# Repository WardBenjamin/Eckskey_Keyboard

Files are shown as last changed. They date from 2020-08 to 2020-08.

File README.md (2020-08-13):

# Eckskey

The Eckskey (pronounced "x key") keyboard is an open source 74% mechanical keyboard, designed with an emphasis on electrical correctness and manufacturability, and with some fun tricks.

## Design Philosophy

Throughout the design, electrical correctness will be emphasized, including proper differential pair routing (within the constraints of a two layer design), ground planes, current carrying capacity, and oscillator routing. The board is manufacturable with 6mil trace/space, accomplishable with 1oz two layer designs by local vendors in your area (including the United States) as well as at the cheapest Chinese vendors like JLCPCB, PCBway, and AllPCB.

The base keyboard is designed to be made in two pieces, meaning that it can be assembled in a small/cheap reflow oven like a ControLEO 3 toaster oven conversion or the common Chinese T962 variants. This adds a small amount of BOM cost and would probably increase the cost at quantity, but enables wider access.

This keyboard is NOT meant to be assembled by the typical r/MK hobbyist - it includes QFN and 0603 parts which require a stencil and a pair of tweezers and a pick and place machine to assemble reasonably. You CAN solder these by hand or with hot air but it is difficult. 

## Fun tricks

In total, the base keyboard is a 74% design, meaning that it retains alphanumerics, function keys (F1-F12), and symbols. In addition, the bottom row has been modified to add a left function key (FN) between left control and META/Windows and a right print screen key between menu and right control. Since it still uses a normal 6.25U spacebar, the right keys in the bottom of the row have each been shrunk to 1U. The function keys have been shifted leftwards and collapsed in order to make space for 1U insert and delete keys above backspace. This retains all common functionality of a 100% keyboard except for nav cluster, media keys, and numpad.

The base keyboard includes an integrated USB hub to allow for additional modules to be connected. Two modules will be made - a numpad and nav cluster+media keys. These will technically be separate keyboards, connected via USB-C and magnetic mounting, and can be used standalone as well. These keyboards also have access to the function key by taking advantage of the SBU pins of the USB-C connectors which are normally unused in a USB 1.1/2.0 implementation.

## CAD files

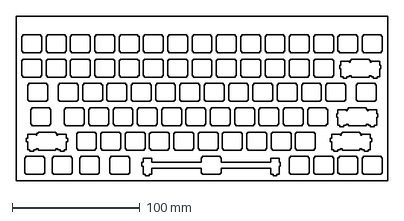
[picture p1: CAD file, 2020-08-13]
mechanical/eckskey_base_74.dxf
290.7 x 128.8 mm

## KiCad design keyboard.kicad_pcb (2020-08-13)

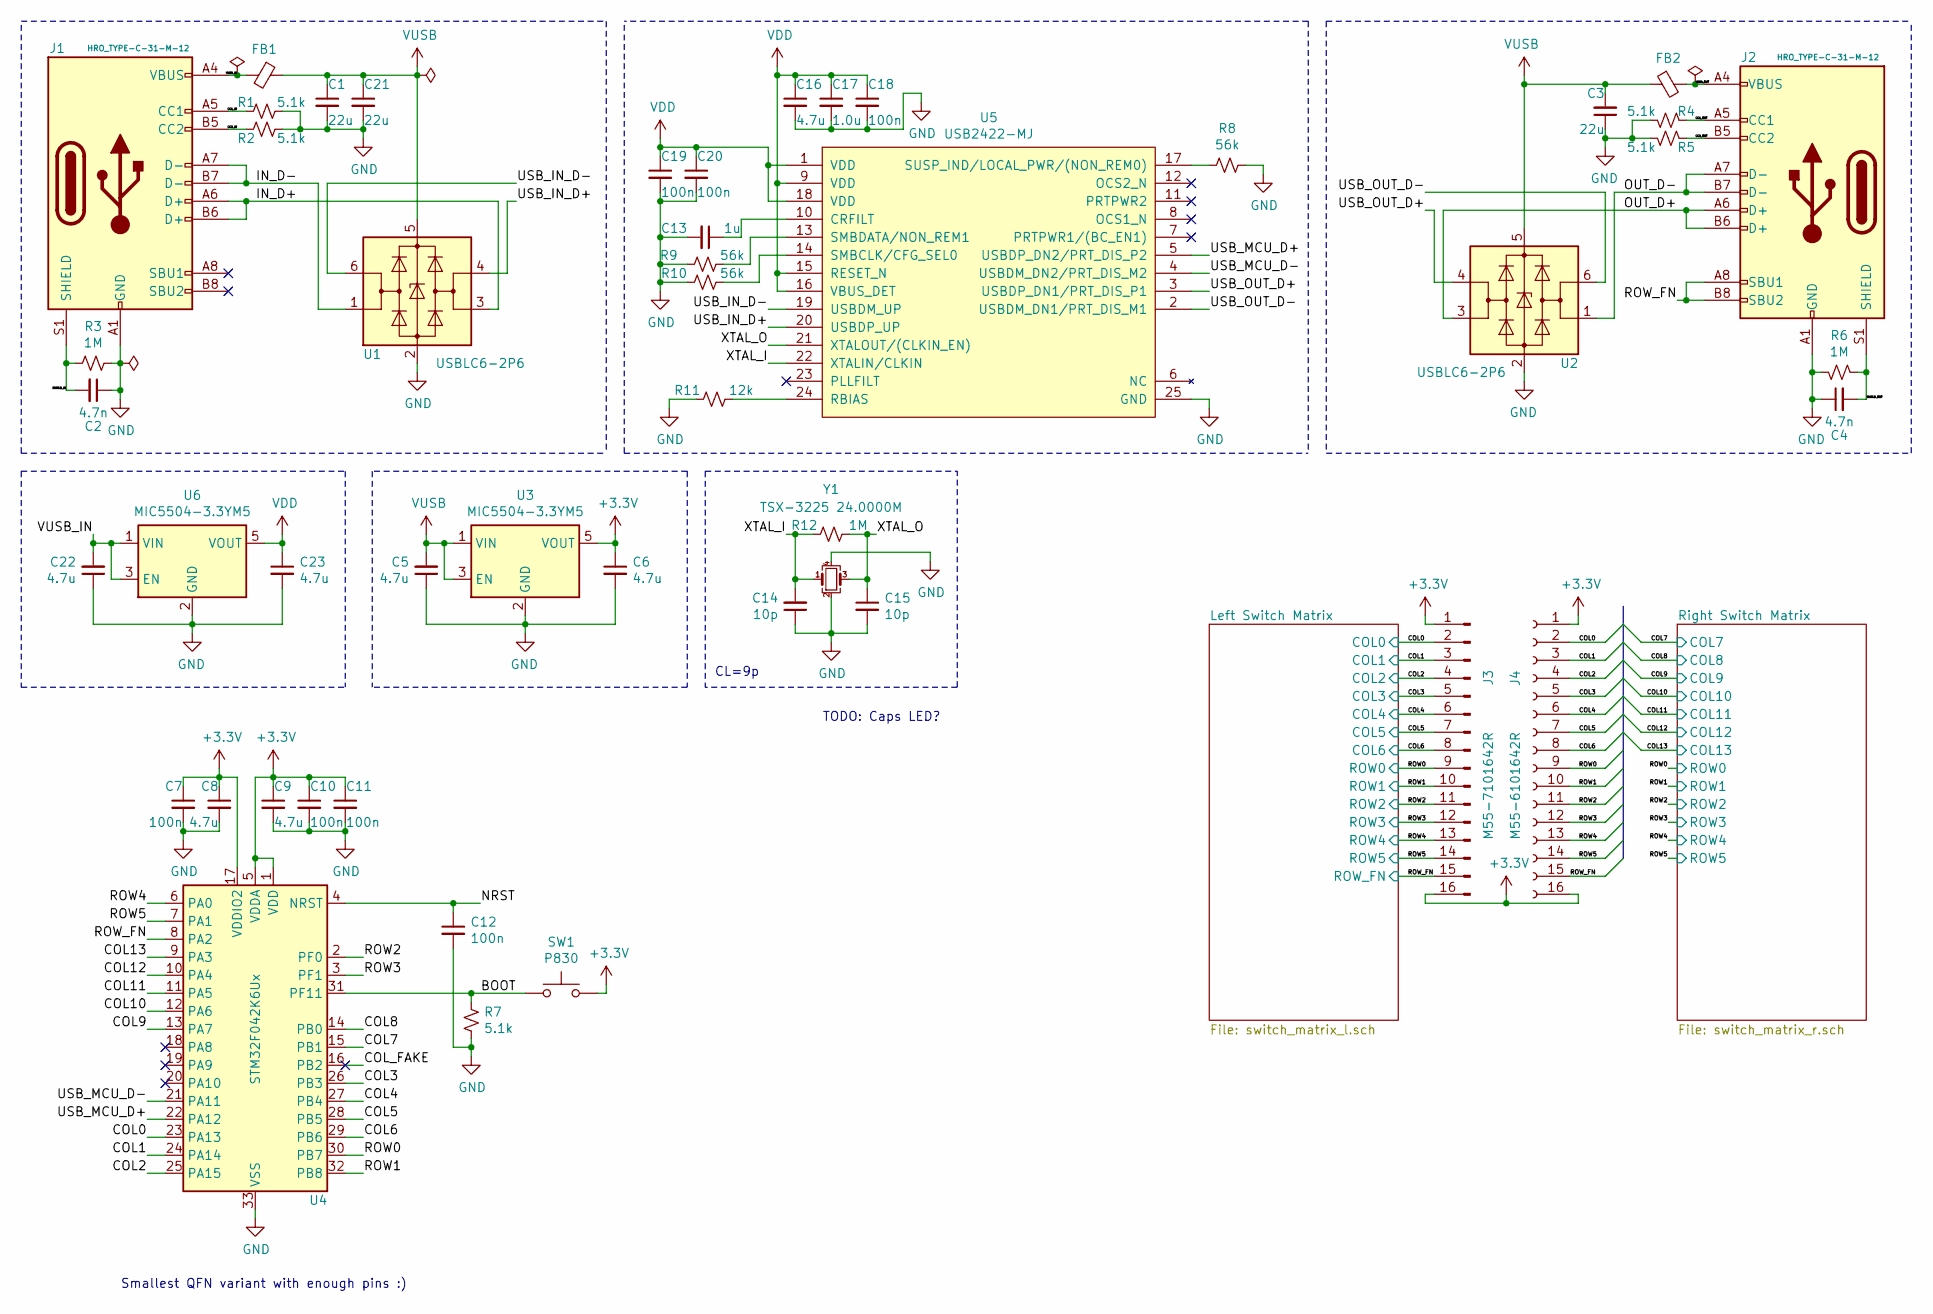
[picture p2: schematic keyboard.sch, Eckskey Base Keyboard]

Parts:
C1, C3, C21: 22u; C_0603_1608Metric
C2, C4: 4.7n; C_0603_1608Metric
C5, C6, C8, C9, C16, C22, C23: 4.7u; C_0603_1608Metric
C7, C10, C11, C12, C18, C19, C20: 100n; C_0603_1608Metric
C13: 1u; C_0603_1608Metric
C14, C15: 10p; C_0603_1608Metric
C17: 1.0u; C_0603_1608Metric
FB1, FB2: Ferrite_Bead_Small; L_0603_1608Metric
J1, J2: HRO_TYPE-C-31-M-12; USB_C_Receptacle_HRO_TYPE-C-31-M-12
J3: M55-7101642R; M557101642R
J4: M55-6101642R; M556101642R
R1, R2, R4, R5, R7: 5.1k; R_0603_1608Metric
R3, R6, R12: 1M; R_0603_1608Metric
R8, R9, R10: 56k; R_0603_1608Metric
R11: 12k; R_0603_1608Metric
SW1: P830; SW_SPST_PTS830
U1, U2: USBLC6-2P6; SOT-666
U3, U6: MIC5504-3.3YM5; SOT-23-5
U4: STM32F042K6Ux; QFN-32-1EP_5x5mm_P0.5mm_EP3.45x3.45mm
U5: USB2422-MJ; QFN-24-1EP_4x4mm_P0.5mm_EP2.7x2.7mm_ThermalVias
Y1: TSX-3225 24.0000M; Crystal_SMD_SeikoEpson_TSX3225-4Pin_3.2x2.5mm

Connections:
+3V3: C6.1, C7.1, C8.1, C9.1, C10.1, C11.1, J3.1, J3.16, J4.1, J4.16, SW1.2, U3.5 (VOUT), U4.1 (VDD), U4.5 (VDDA), U4.17 (VDDIO2); also elsewhere on the board
/BOOT: R7.1, SW1.1, U4.31 (PF11)
/CC1_IN: J1.A5 (CC1), R1.2
/CC1_OUT: J2.A5 (CC1), R4.2
/CC2_IN: J1.B5 (CC2), R2.2
/CC2_OUT: J2.B5 (CC2), R5.2
/COL0: J3.2, J4.2, U4.23 (PA13); also elsewhere on the board
/COL1: J3.3, J4.3, U4.24 (PA14); also elsewhere on the board
/COL2: J3.4, J4.4, U4.25 (PA15); also elsewhere on the board
/COL3: J3.5, J4.5, U4.26 (PB3); also elsewhere on the board
/COL4: J3.6, J4.6, U4.27 (PB4); also elsewhere on the board
/COL5: J3.7, J4.7, U4.28 (PB5); also elsewhere on the board
/COL6: J3.8, J4.8, U4.29 (PB6); also elsewhere on the board
/COL7: U4.15 (PB1); also elsewhere on the board
/COL8: U4.14 (PB0); also elsewhere on the board
/COL9: U4.13 (PA7); also elsewhere on the board
/COL10: U4.12 (PA6); also elsewhere on the board
/COL11: U4.11 (PA5); also elsewhere on the board
/COL12: U4.10 (PA4); also elsewhere on the board
/COL13: U4.9 (PA3); also elsewhere on the board
/IN_D+: J1.A6 (D+), J1.B6 (D+), U1.3 (I/O2)
/IN_D-: J1.A7 (D-), J1.B7 (D-), U1.1 (I/O1)
/NRST: C12.1, U4.4 (NRST)
/OUT_D+: J2.A6 (D+), J2.B6 (D+), U2.3 (I/O2)
/OUT_D-: J2.A7 (D-), J2.B7 (D-), U2.1 (I/O1)
/ROW0: J3.9, J4.9, U4.30 (PB7); also elsewhere on the board
/ROW1: J3.10, J4.10, U4.32 (PB8); also elsewhere on the board
/ROW2: J3.11, J4.11, U4.2 (PF0); also elsewhere on the board
/ROW3: J3.12, J4.12, U4.3 (PF1); also elsewhere on the board
/ROW4: J3.13, J4.13, U4.6 (PA0); also elsewhere on the board
/ROW5: J3.14, J4.14, U4.7 (PA1); also elsewhere on the board
/ROW_FN: J2.A8 (SBU1), J2.B8 (SBU2), J3.15, J4.15, U4.8 (PA2); also elsewhere on the board
/SHIELD_IN: C2.2, J1.S1 (SHIELD), R3.2
/SHIELD_OUT: C4.2, J2.S1 (SHIELD), R6.2
/USB_IN_D+: U1.4 (I/O2), U5.20 (USBDP_UP)
/USB_IN_D-: U1.6 (I/O1), U5.19 (USBDM_UP)
/USB_MCU_D+: U4.22 (PA12), U5.5 (USBDP_DN2/PRT_DIS_P2)
/USB_MCU_D-: U4.21 (PA11), U5.4 (USBDM_DN2/PRT_DIS_M2)
/USB_OUT_D+: U2.4 (I/O2), U5.3 (USBDP_DN1/PRT_DIS_P1)
/USB_OUT_D-: U2.6 (I/O1), U5.2 (USBDM_DN1/PRT_DIS_M1)
/VUSB_IN: C22.2, FB1.2, J1.A4 (VBUS), J1.A9 (VBUS), J1.B4 (VBUS), J1.B9 (VBUS), U6.1 (VIN), U6.3 (EN)
/VUSB_OUT: FB2.2, J2.A4 (VBUS), J2.A9 (VBUS), J2.B4 (VBUS), J2.B9 (VBUS)
/XTAL_I: C14.2, R12.2, U5.22 (XTALIN/CLKIN), Y1.1
/XTAL_O: C15.1, R12.1, U5.21 (XTALOUT/(CLKIN_EN)), Y1.3
GND: C1.2, C2.1, C3.1, C4.1, C5.1, C6.2, C7.2, C8.2, C9.2, C10.2, C11.2, C12.2, C13.2, C14.1, C15.2, C16.2, C17.2, C18.2, C19.2, C20.2, C21.2, C22.1, C23.2, J1.A1 (GND), J1.A12 (GND), J1.B1 (GND), J1.B12 (GND), J2.A1 (GND), J2.A12 (GND), J2.B1 (GND), J2.B12 (GND), R1.1, R2.1, R3.1, R4.1, R5.1, R6.1, R7.2, R8.1, R9.2, R10.2, R11.2, U1.2 (GND), U2.2 (GND), U3.2 (GND), U4.33 (VSS), U5.25 (GND), U6.2 (GND), Y1.2, Y1.4
unnamed: C13.1, U5.10 (CRFILT)
unnamed: R8.2, U5.17 (SUSP_IND/LOCAL_PWR/(NON_REM0))
unnamed: R9.1, U5.13 (SMBDATA/NON_REM1)
unnamed: R10.1, U5.14 (SMBCLK/CFG_SEL0)
unnamed: R11.1, U5.24 (RBIAS)
VDD: C16.1, C17.1, C18.1, C19.1, C20.1, C23.1, U5.1 (VDD), U5.9 (VDD), U5.15 (RESET_N), U5.16 (VBUS_DET), U5.18 (VDD), U6.5 (VOUT)
VUSB: C1.1, C3.2, C5.2, C21.1, FB1.1, FB2.1, U1.5 (VBUS), U2.5 (VBUS), U3.1 (VIN), U3.3 (EN)

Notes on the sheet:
Smallest QFN variant with enough pins :)
CL=9p
TODO: Caps LED?

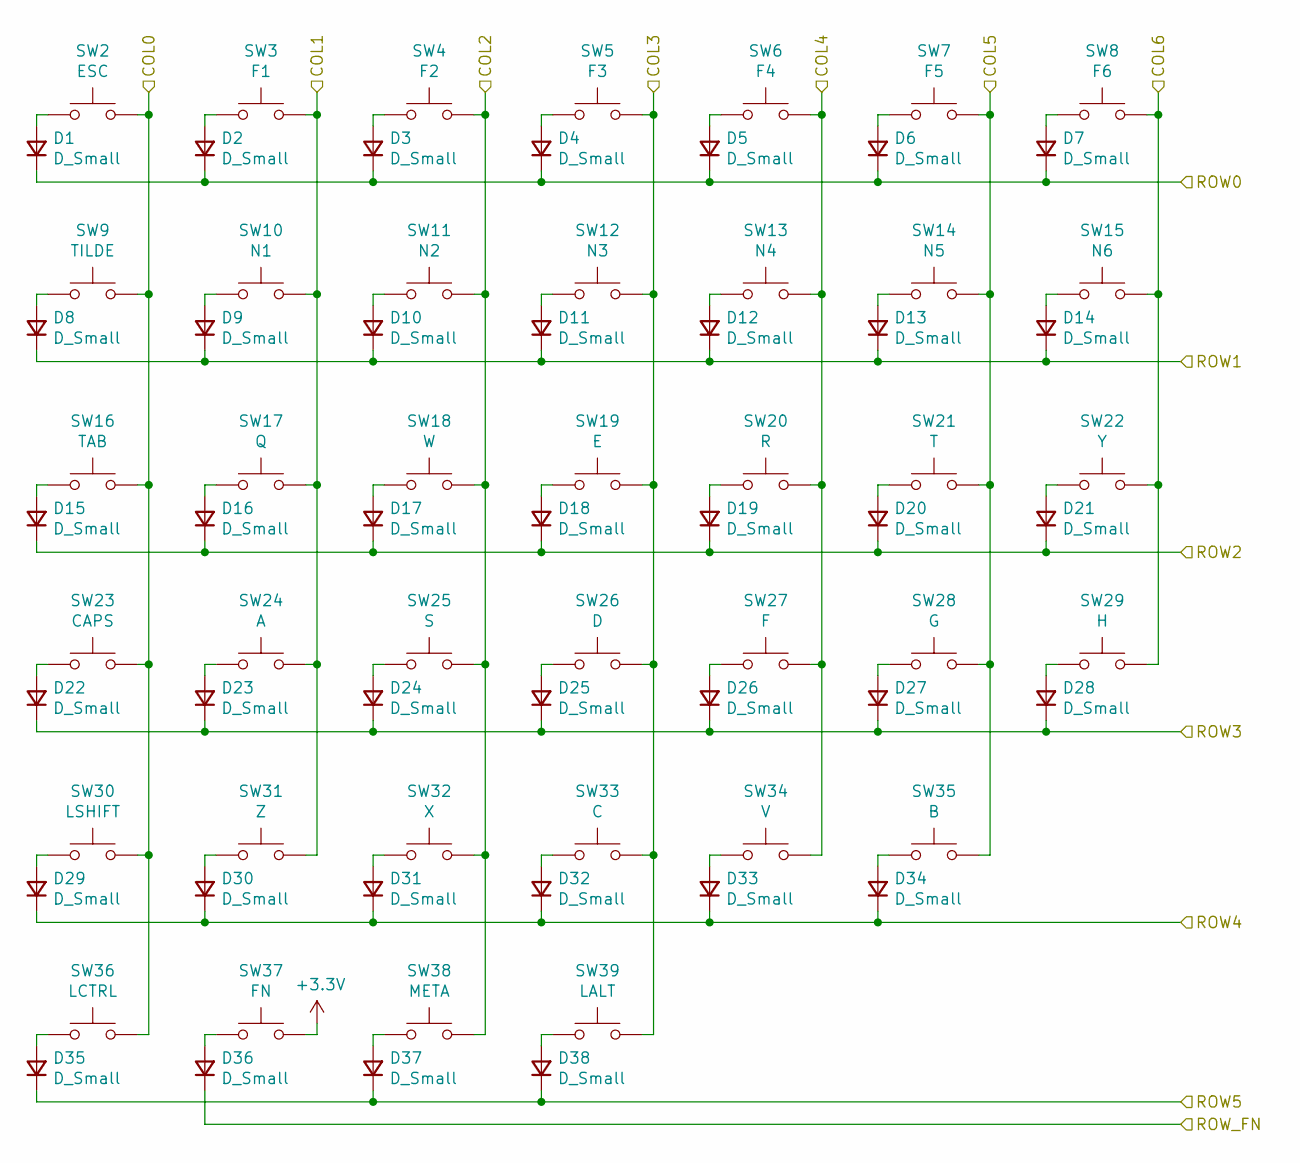
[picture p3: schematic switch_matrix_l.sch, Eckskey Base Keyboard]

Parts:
D1, D2, D3, D4, D5, D6, D7, D8, D9, D10, D11, D12, D13, D14, D15, D16, D17, D18, D19, D20, D21, D22, D23, D24, D25, D26, D27, D28, D29, D30, D31, D32, D33, D34, D35, D36, D37, D38: D_Small; D_SOD-123F
SW2: ESC; MX-1U
SW3: F1; MX-1U
SW4: F2; MX-1U
SW5: F3; MX-1U
SW6: F4; MX-1U
SW7: F5; MX-1U
SW8: F6; MX-1U
SW9: TILDE; MX-1U
SW10: N1; MX-1U
SW11: N2; MX-1U
SW12: N3; MX-1U
SW13: N4; MX-1U
SW14: N5; MX-1U
SW15: N6; MX-1U
SW16: TAB; MX-1.5U
SW17: Q; MX-1U
SW18: W; MX-1U
SW19: E; MX-1U
SW20: R; MX-1U
SW21: T; MX-1U
SW22: Y; MX-1U
SW23: CAPS; MX-1.75U
SW24: A; MX-1U
SW25: S; MX-1U
SW26: D; MX-1U
SW27: F; MX-1U
SW28: G; MX-1U
SW29: H; MX-1U
SW30: LSHIFT; MX-2.25U
SW31: Z; MX-1U
SW32: X; MX-1U
SW33: C; MX-1U
SW34: V; MX-1U
SW35: B; MX-1U
SW36: LCTRL; MX-1.25U
SW37: FN; MX-1U
SW38: META; MX-1.25U
SW39: LALT; MX-1.25U

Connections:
+3V3: SW37.2; also elsewhere on the board
/COL0: SW2.2, SW9.2, SW16.2, SW23.2, SW30.2, SW36.2; also elsewhere on the board
/COL1: SW3.2, SW10.2, SW17.2, SW24.2, SW31.2; also elsewhere on the board
/COL2: SW4.2, SW11.2, SW18.2, SW25.2, SW32.2, SW38.2; also elsewhere on the board
/COL3: SW5.2, SW12.2, SW19.2, SW26.2, SW33.2, SW39.2; also elsewhere on the board
/COL4: SW6.2, SW13.2, SW20.2, SW27.2, SW34.2; also elsewhere on the board
/COL5: SW7.2, SW14.2, SW21.2, SW28.2, SW35.2; also elsewhere on the board
/COL6: SW8.2, SW15.2, SW22.2, SW29.2; also elsewhere on the board
/ROW0: D1.1 (K), D2.1 (K), D3.1 (K), D4.1 (K), D5.1 (K), D6.1 (K), D7.1 (K); also elsewhere on the board
/ROW1: D8.1 (K), D9.1 (K), D10.1 (K), D11.1 (K), D12.1 (K), D13.1 (K), D14.1 (K); also elsewhere on the board
/ROW2: D15.1 (K), D16.1 (K), D17.1 (K), D18.1 (K), D19.1 (K), D20.1 (K), D21.1 (K); also elsewhere on the board
/ROW3: D22.1 (K), D23.1 (K), D24.1 (K), D25.1 (K), D26.1 (K), D27.1 (K), D28.1 (K); also elsewhere on the board
/ROW4: D29.1 (K), D30.1 (K), D31.1 (K), D32.1 (K), D33.1 (K), D34.1 (K); also elsewhere on the board
/ROW5: D35.1 (K), D37.1 (K), D38.1 (K); also elsewhere on the board
/ROW_FN: D36.1 (K); also elsewhere on the board
unnamed: D1.2 (A), SW2.1
unnamed: D2.2 (A), SW3.1
unnamed: D3.2 (A), SW4.1
unnamed: D4.2 (A), SW5.1
unnamed: D5.2 (A), SW6.1
unnamed: D6.2 (A), SW7.1
unnamed: D7.2 (A), SW8.1
unnamed: D8.2 (A), SW9.1
unnamed: D9.2 (A), SW10.1
unnamed: D10.2 (A), SW11.1
unnamed: D11.2 (A), SW12.1
unnamed: D12.2 (A), SW13.1
unnamed: D13.2 (A), SW14.1
unnamed: D14.2 (A), SW15.1
unnamed: D15.2 (A), SW16.1
unnamed: D16.2 (A), SW17.1
unnamed: D17.2 (A), SW18.1
unnamed: D18.2 (A), SW19.1
unnamed: D19.2 (A), SW20.1
unnamed: D20.2 (A), SW21.1
unnamed: D21.2 (A), SW22.1
unnamed: D22.2 (A), SW23.1
unnamed: D23.2 (A), SW24.1
unnamed: D24.2 (A), SW25.1
unnamed: D25.2 (A), SW26.1
unnamed: D26.2 (A), SW27.1
unnamed: D27.2 (A), SW28.1
unnamed: D28.2 (A), SW29.1
unnamed: D29.2 (A), SW30.1
unnamed: D30.2 (A), SW31.1
unnamed: D31.2 (A), SW32.1
unnamed: D32.2 (A), SW33.1
unnamed: D33.2 (A), SW34.1
unnamed: D34.2 (A), SW35.1
unnamed: D35.2 (A), SW36.1
unnamed: D36.2 (A), SW37.1
unnamed: D37.2 (A), SW38.1
unnamed: D38.2 (A), SW39.1

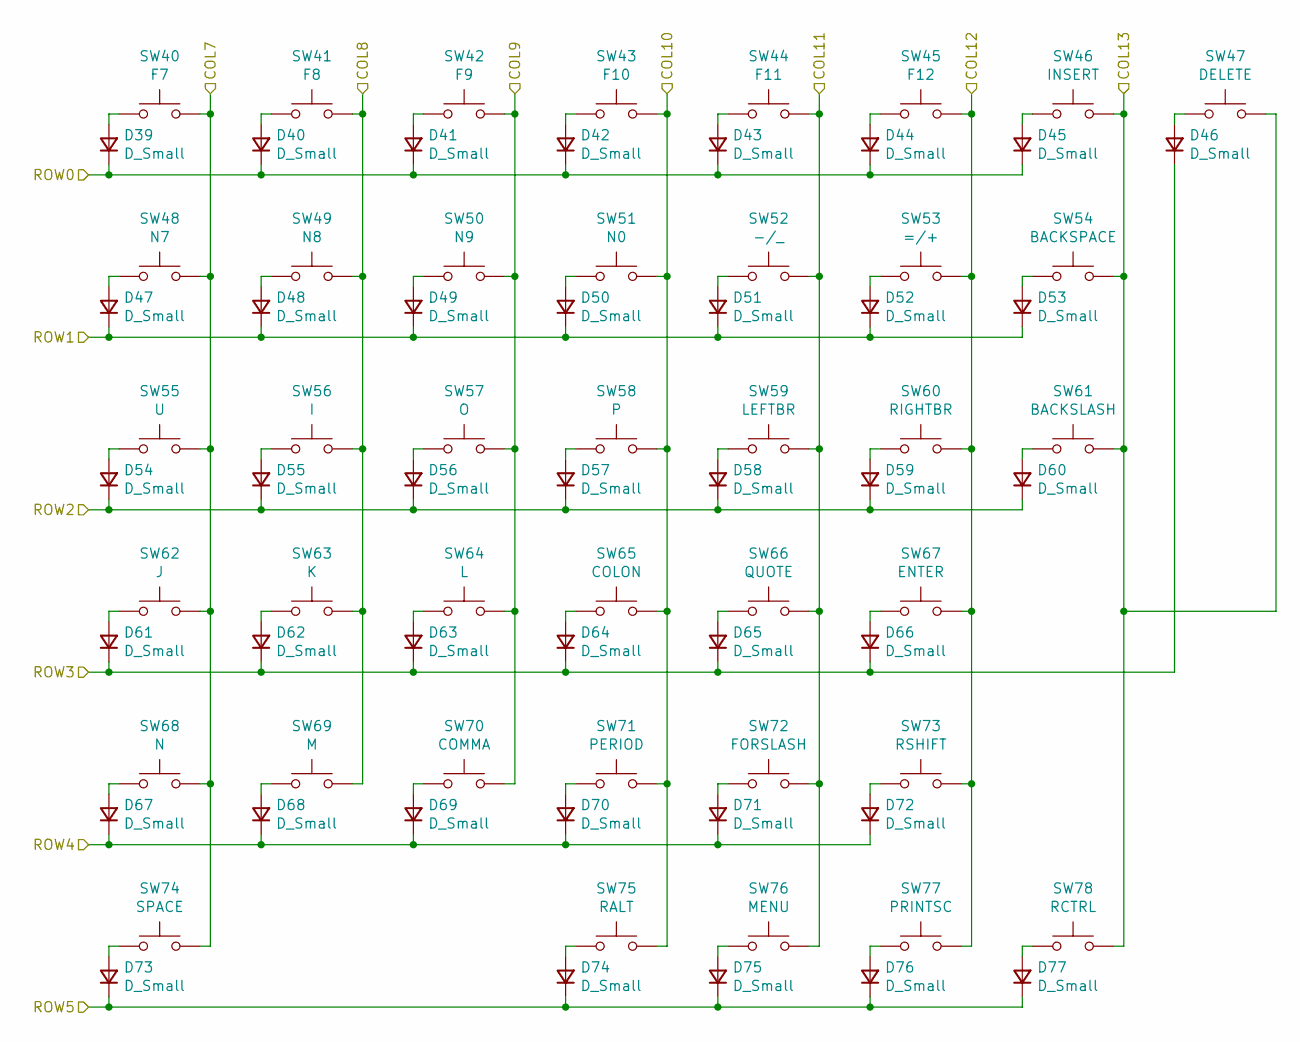
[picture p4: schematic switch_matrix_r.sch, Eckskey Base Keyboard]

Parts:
D39, D40, D41, D42, D43, D44, D45, D46, D47, D48, D49, D50, D51, D52, D53, D54, D55, D56, D57, D58, D59, D60, D61, D62, D63, D64, D65, D66, D67, D68, D69, D70, D71, D72, D73, D74, D75, D76, D77: D_Small; D_SOD-123F
SW40: F7; MX-1U
SW41: F8; MX-1U
SW42: F9; MX-1U
SW43: F10; MX-1U
SW44: F11; MX-1U
SW45: F12; MX-1U
SW46: INSERT; MX-1U
SW47: DELETE; MX-1U
SW48: N7; MX-1U
SW49: N8; MX-1U
SW50: N9; MX-1U
SW51: N0; MX-1U
SW52: -/_; MX-1U
SW53: =/+; MX-1U
SW54: BACKSPACE; MX-2U
SW55: U; MX-1U
SW56: I; MX-1U
SW57: O; MX-1U
SW58: P; MX-1U
SW59: LEFTBR; MX-1U
SW60: RIGHTBR; MX-1U
SW61: BACKSLASH; MX-1.5U
SW62: J; MX-1U
SW63: K; MX-1U
SW64: L; MX-1U
SW65: COLON; MX-1U
SW66: QUOTE; MX-1U
SW67: ENTER; MX-2.25U
SW68: N; MX-1U
SW69: M; MX-1U
SW70: COMMA; MX-1U
SW71: PERIOD; MX-1U
SW72: FORSLASH; MX-1U
SW73: RSHIFT; MX-2.75U
SW74: SPACE; MX-6.25U
SW75: RALT; MX-1U
SW76: MENU; MX-1U
SW77: PRINTSC; MX-1U
SW78: RCTRL; MX-1U

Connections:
/COL7: SW40.2, SW48.2, SW55.2, SW62.2, SW68.2, SW74.2; also elsewhere on the board
/COL8: SW41.2, SW49.2, SW56.2, SW63.2, SW69.2; also elsewhere on the board
/COL9: SW42.2, SW50.2, SW57.2, SW64.2, SW70.2; also elsewhere on the board
/COL10: SW43.2, SW51.2, SW58.2, SW65.2, SW71.2, SW75.2; also elsewhere on the board
/COL11: SW44.2, SW52.2, SW59.2, SW66.2, SW72.2, SW76.2; also elsewhere on the board
/COL12: SW45.2, SW53.2, SW60.2, SW67.2, SW73.2, SW77.2; also elsewhere on the board
/COL13: SW46.2, SW47.2, SW54.2, SW61.2, SW78.2; also elsewhere on the board
/ROW0: D39.1 (K), D40.1 (K), D41.1 (K), D42.1 (K), D43.1 (K), D44.1 (K), D45.1 (K); also elsewhere on the board
/ROW1: D47.1 (K), D48.1 (K), D49.1 (K), D50.1 (K), D51.1 (K), D52.1 (K), D53.1 (K); also elsewhere on the board
/ROW2: D54.1 (K), D55.1 (K), D56.1 (K), D57.1 (K), D58.1 (K), D59.1 (K), D60.1 (K); also elsewhere on the board
/ROW3: D46.1 (K), D61.1 (K), D62.1 (K), D63.1 (K), D64.1 (K), D65.1 (K), D66.1 (K); also elsewhere on the board
/ROW4: D67.1 (K), D68.1 (K), D69.1 (K), D70.1 (K), D71.1 (K), D72.1 (K); also elsewhere on the board
/ROW5: D73.1 (K), D74.1 (K), D75.1 (K), D76.1 (K), D77.1 (K); also elsewhere on the board
unnamed: D39.2 (A), SW40.1
unnamed: D40.2 (A), SW41.1
unnamed: D41.2 (A), SW42.1
unnamed: D42.2 (A), SW43.1
unnamed: D43.2 (A), SW44.1
unnamed: D44.2 (A), SW45.1
unnamed: D45.2 (A), SW46.1
unnamed: D46.2 (A), SW47.1
unnamed: D47.2 (A), SW48.1
unnamed: D48.2 (A), SW49.1
unnamed: D49.2 (A), SW50.1
unnamed: D50.2 (A), SW51.1
unnamed: D51.2 (A), SW52.1
unnamed: D52.2 (A), SW53.1
unnamed: D53.2 (A), SW54.1
unnamed: D54.2 (A), SW55.1
unnamed: D55.2 (A), SW56.1
unnamed: D56.2 (A), SW57.1
unnamed: D57.2 (A), SW58.1
unnamed: D58.2 (A), SW59.1
unnamed: D59.2 (A), SW60.1
unnamed: D60.2 (A), SW61.1
unnamed: D61.2 (A), SW62.1
unnamed: D62.2 (A), SW63.1
unnamed: D63.2 (A), SW64.1
unnamed: D64.2 (A), SW65.1
unnamed: D65.2 (A), SW66.1
unnamed: D66.2 (A), SW67.1
unnamed: D67.2 (A), SW68.1
unnamed: D68.2 (A), SW69.1
unnamed: D69.2 (A), SW70.1
unnamed: D70.2 (A), SW71.1
unnamed: D71.2 (A), SW72.1
unnamed: D72.2 (A), SW73.1
unnamed: D73.2 (A), SW74.1
unnamed: D74.2 (A), SW75.1
unnamed: D75.2 (A), SW76.1
unnamed: D76.2 (A), SW77.1
unnamed: D77.2 (A), SW78.1

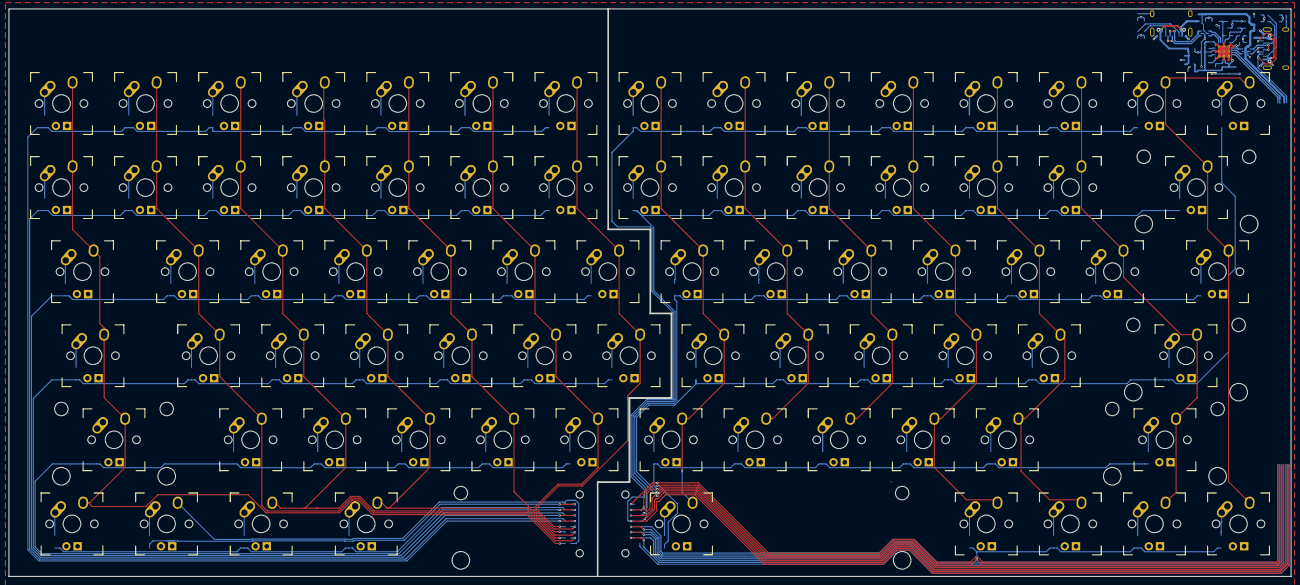
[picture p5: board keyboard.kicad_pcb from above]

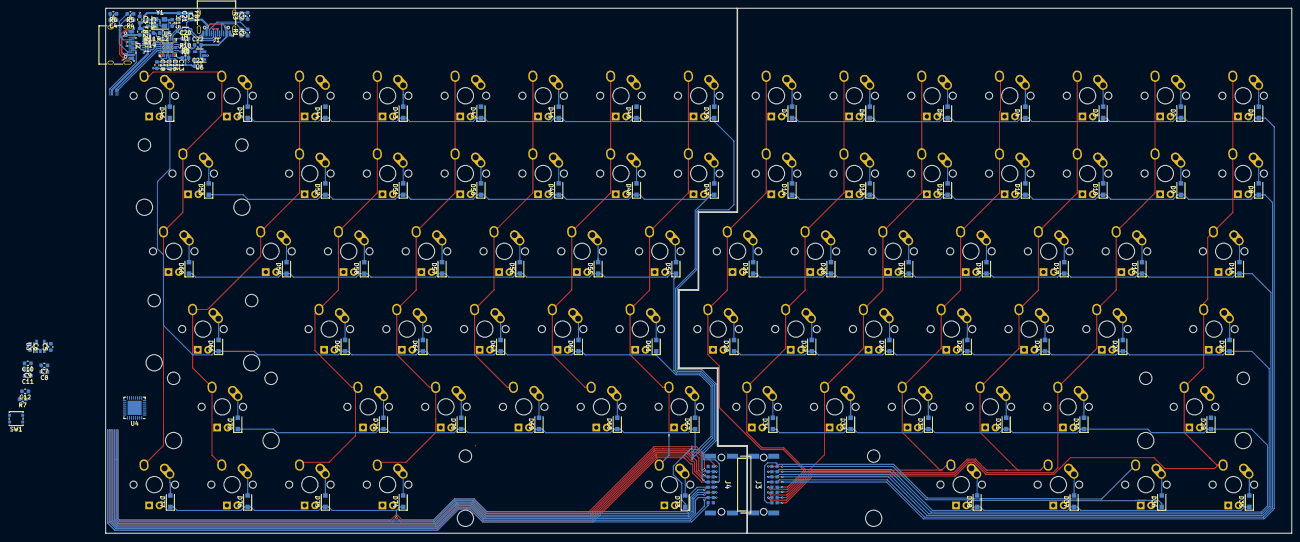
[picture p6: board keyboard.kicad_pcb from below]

Board: 2 copper layers, 290.5 x 128.6 mm, 203 parts (126 on the bottom side), 129 nets.

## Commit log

2020-08-13 Initial commit; base keyboard 90% complete
    [eckskey_base_74.dxf, keyboard.kicad_pcb, keyboard.sch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]
2020-08-13 Add TODO notes to schematic
    [keyboard.sch]
